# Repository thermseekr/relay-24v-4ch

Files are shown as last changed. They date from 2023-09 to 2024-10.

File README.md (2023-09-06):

# RELAY-24V-4CH

Relay board with 4x 24 VDC relays. This board is designed to be used togheter with [ESP-24V-16CH](https://github.com/thermseekr/esp-24v-16ch) and [ESP-24V-32CH](https://github.com/thermseekr/esp-24v-32ch), but can be driven by any 24V control circuit compatible with NPN inputs.

The dimensions are such that the boards can be mounted on a PCB DIN rail holder from the Brazilian manufacturer Metaltex, check [here](https://www.metaltex.com.br/produtos/componentes/suportes/sp7-suporte-para-montagem-de-placa-de-circuito-impresso-em-trilho-din) for details.

Board V1 uses Omron 16A relays and is limited to 12A/channel, board V2 uses Omron 10A relays and is limited to 8A/channel. The current limits are imposed per copper trace capacity.

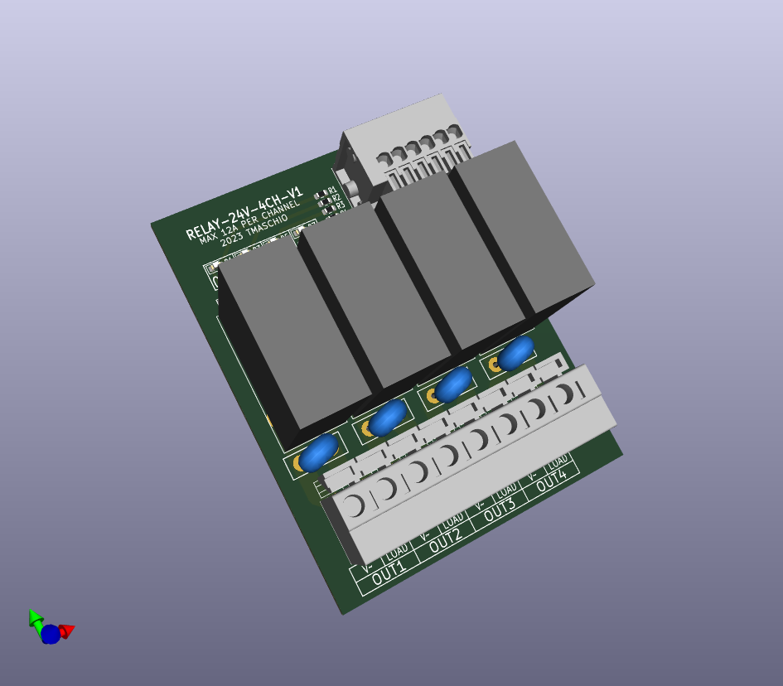
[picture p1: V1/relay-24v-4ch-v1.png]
RELAY-24V-4CH V1


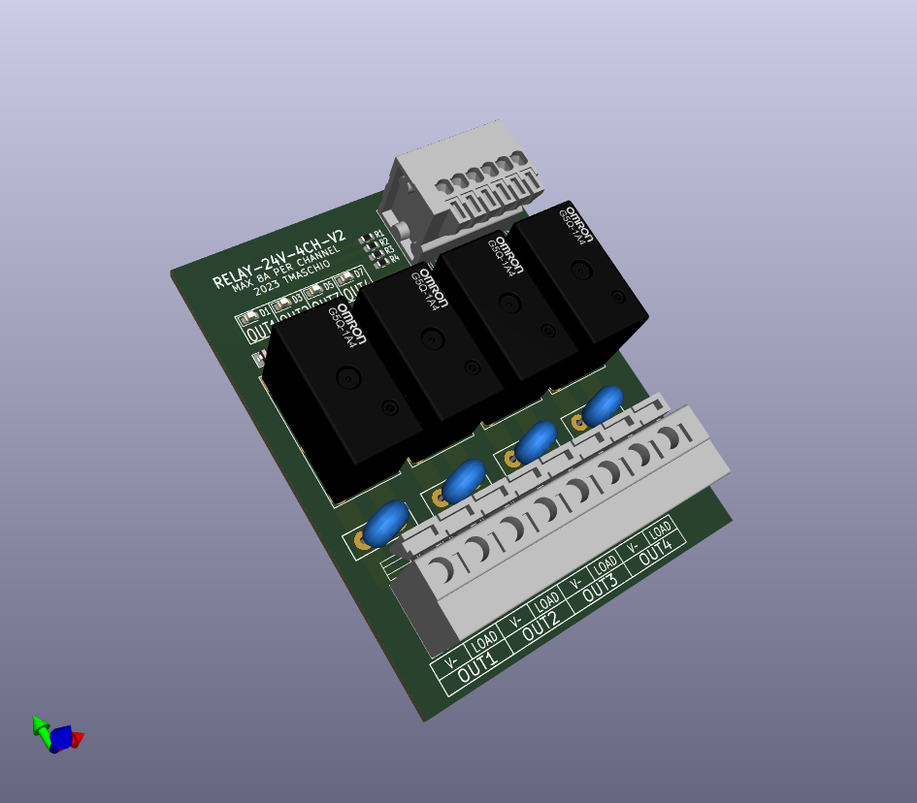
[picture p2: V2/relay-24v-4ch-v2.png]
RELAY-24V-4CH V2


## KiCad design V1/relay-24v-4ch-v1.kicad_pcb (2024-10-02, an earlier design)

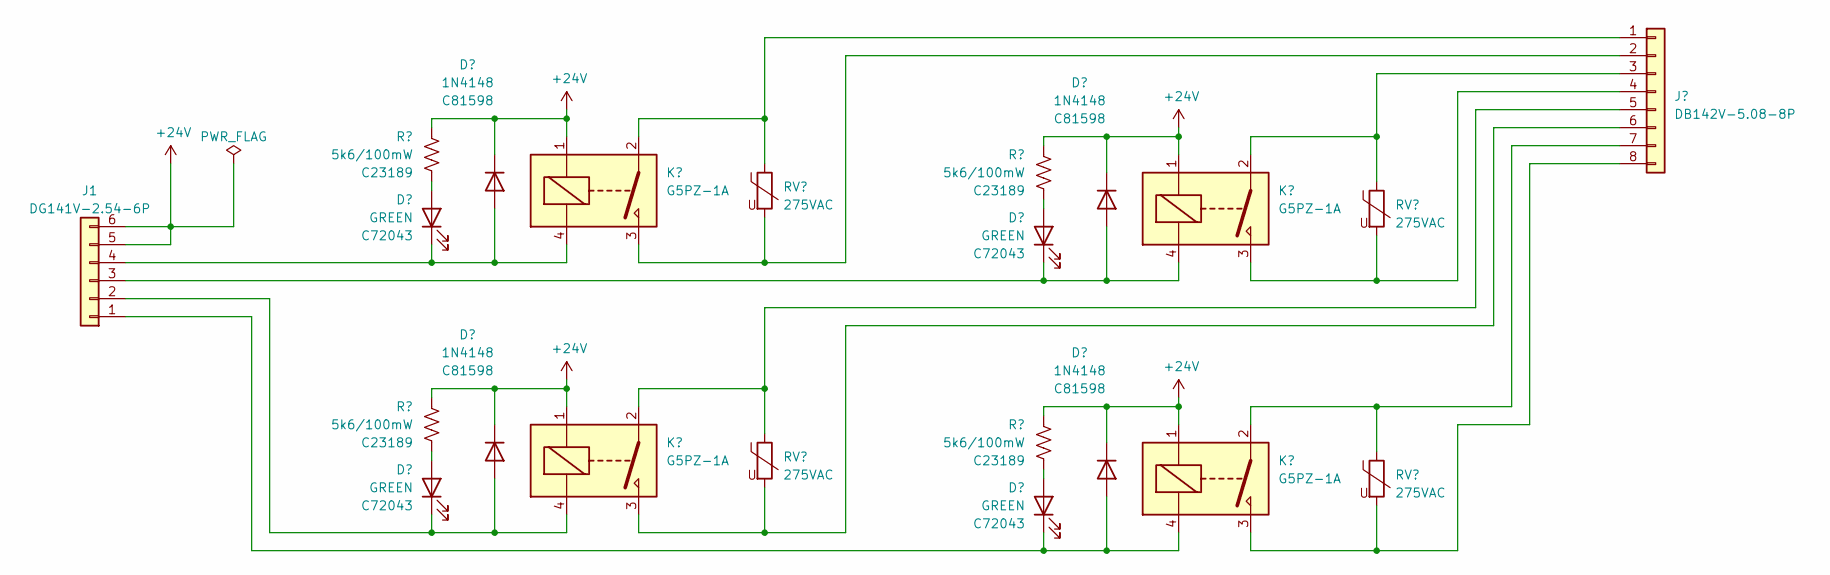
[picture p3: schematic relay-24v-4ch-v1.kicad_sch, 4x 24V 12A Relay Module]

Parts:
D1, D3, D5, D7: GREEN; LED_0603_1608Metric; Mfr PN 19-217/GHC-YR1S2/3T; LCSC Part # C72043
D2, D4, D6, D8: 1N4148; D_SOD-123; Mfr PN 1N4148W; LCSC Part # C81598
J1: DG141V-2.54-6P; TerminalBlock_Dibo_DB141V-2.54-6P_1x06_P2.54mm_Vertical; Mfr PN DB141V-2.54-5P; JLCPCB BOM 1
J2: DB142V-5.08-8P; TerminalBlock_Dibo_DB142V-5.08-8P_1x08_P5.08mm_Vertical; Mfr PN DB142V-5.08-8P; JLCPCB BOM 1
K1, K2, K3, K4: G5PZ-1A; Relay_SPST_Omron_G5PZ-1A; Mfr PN G5PZ-1A; JLCPCB BOM 0
R1, R2, R3, R4: 5k6/100mW; R_0603_1608Metric; Mfr PN 0805W8F4701T5E; LCSC Part # C23189
RV1, RV2, RV3, RV4: 275VAC; RV_Disc_D9.50mm_W3.6mm_P5.08mm; Mfr PN RM07D431KC1IE100; JLCPCB BOM 1

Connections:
+24V: D2.1 (K), D4.1 (K), D6.1 (K), D8.1 (K), J1.5, J1.6, K1.1, K2.1, K3.1, K4.1, R1.1, R2.1, R3.1, R4.1
unnamed: D1.2 (A), R1.2
unnamed: D1.1 (K), D2.2 (A), J1.4, K1.4
unnamed: D3.2 (A), R2.2
unnamed: D3.1 (K), D4.2 (A), J1.3, K2.4
unnamed: D5.2 (A), R3.2
unnamed: D5.1 (K), D6.2 (A), J1.2, K3.4
unnamed: D7.2 (A), R4.2
unnamed: D7.1 (K), D8.2 (A), J1.1, K4.4
unnamed: J2.1, K1.2, RV1.1
unnamed: J2.2, K1.3, RV1.2
unnamed: J2.3, K2.2, RV2.1
unnamed: J2.4, K2.3, RV2.2
unnamed: J2.5, K3.2, RV3.1
unnamed: J2.6, K3.3, RV3.2
unnamed: J2.7, K4.2, RV4.1
unnamed: J2.8, K4.3, RV4.2

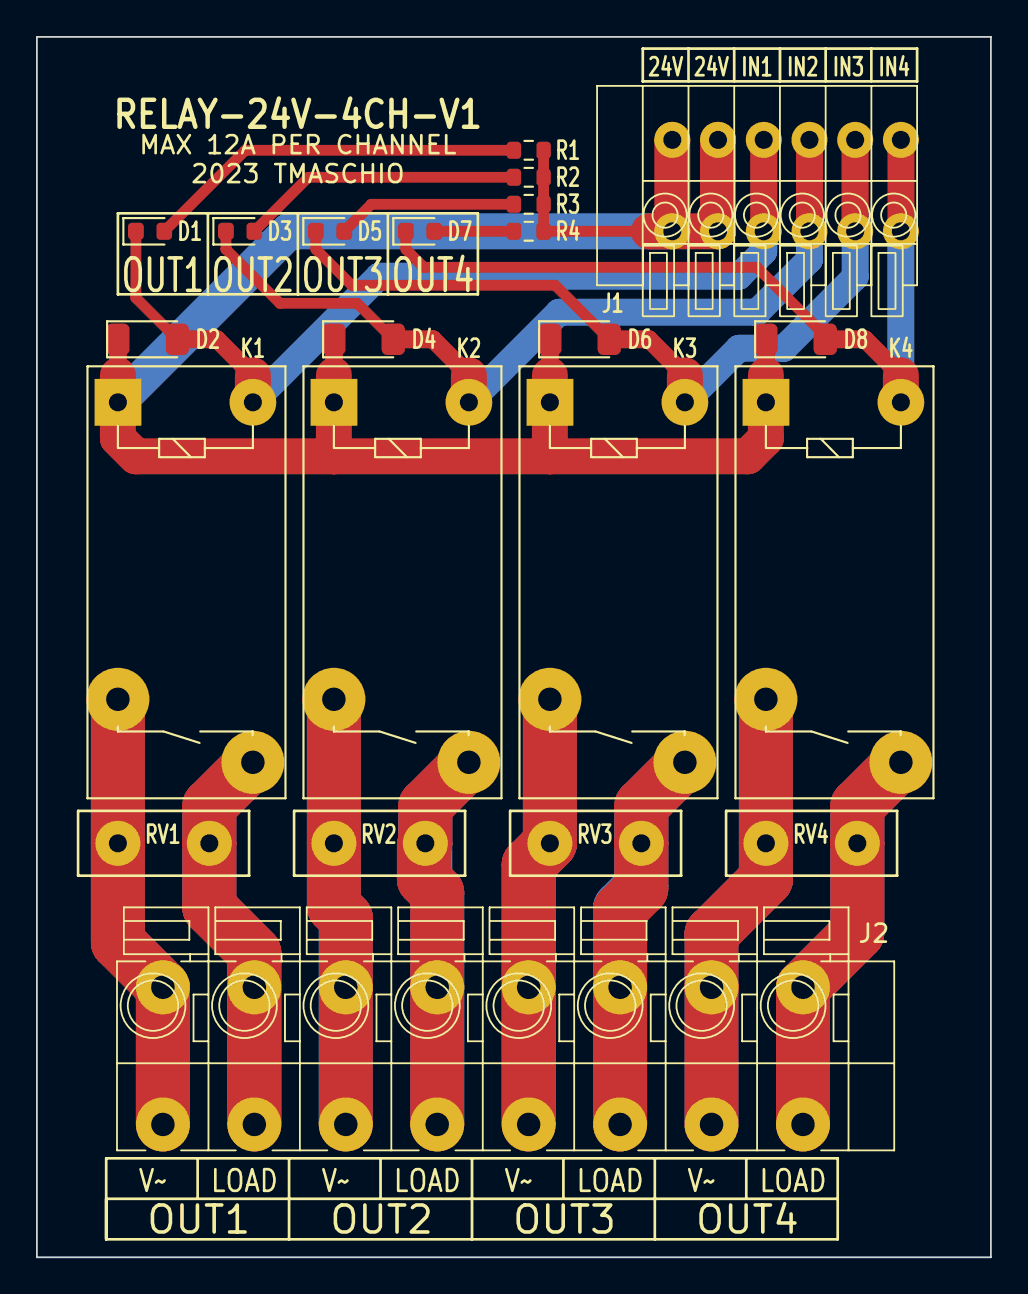
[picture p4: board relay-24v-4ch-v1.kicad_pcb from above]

Board: 2 copper layers, 53.0 x 67.8 mm, 22 parts (0 on the bottom side), 17 nets.

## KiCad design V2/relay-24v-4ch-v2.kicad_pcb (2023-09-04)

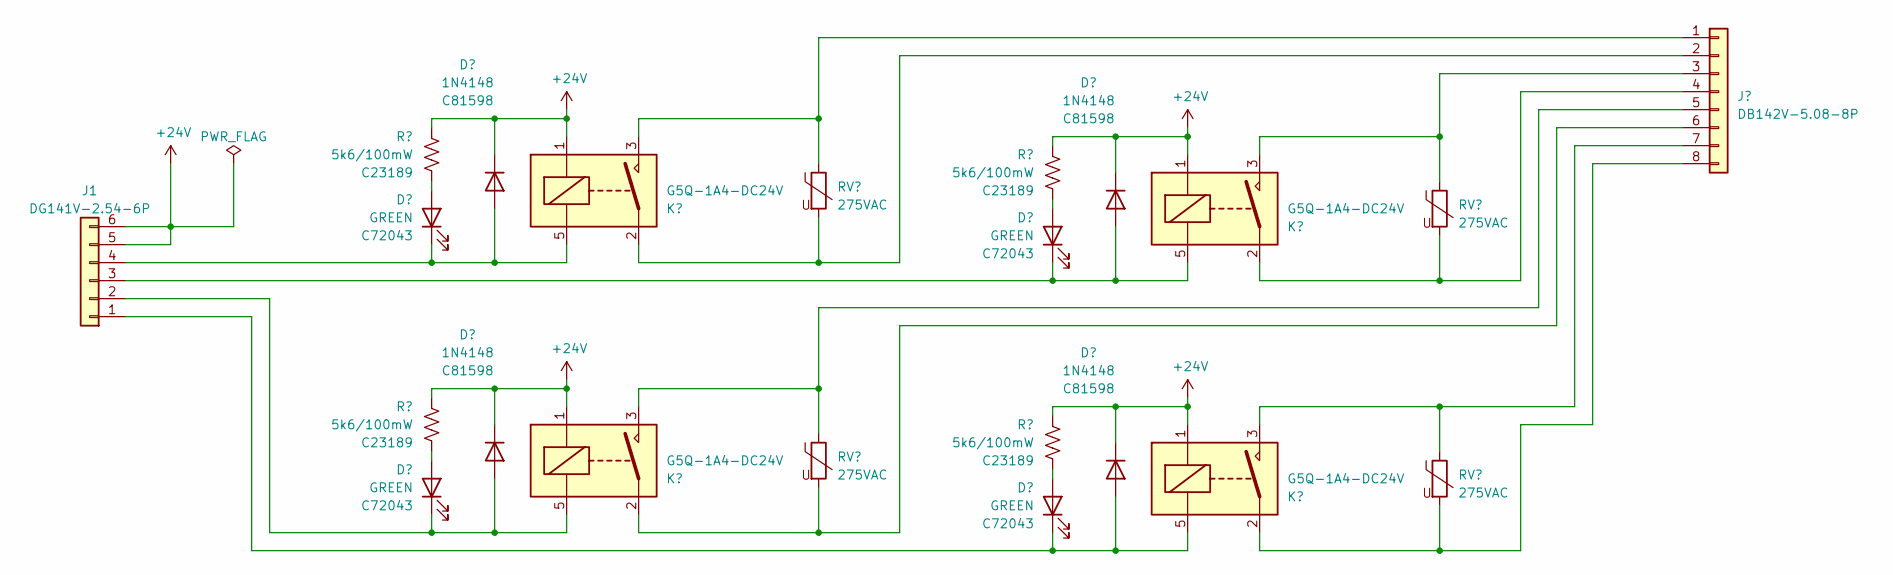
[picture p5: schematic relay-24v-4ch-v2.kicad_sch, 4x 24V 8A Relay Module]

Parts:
D1, D3, D5, D7: GREEN; LED_0603_1608Metric; Mfr PN 19-217/GHC-YR1S2/3T; LCSC Part # C72043
D2, D4, D6, D8: 1N4148; D_SOD-123; Mfr PN 1N4148W; LCSC Part # C81598
J1: DG141V-2.54-6P; TerminalBlock_Dibo_DB141V-2.54-6P_1x06_P2.54mm_Vertical; Mfr PN DB141V-2.54-5P; JLCPCB BOM 1
J2: DB142V-5.08-8P; TerminalBlock_Dibo_DB142V-5.08-8P_1x08_P5.08mm_Vertical; Mfr PN DB142V-5.08-8P; JLCPCB BOM 1
K1, K2, K3, K4: G5Q-1A4-DC24V; Relay_SPST_Omron-G5Q-1A; Mfr PN G5Q-1A4-DC24V; JLCPCB BOM 1
R1, R2, R3, R4: 5k6/100mW; R_0603_1608Metric; Mfr PN 0805W8F4701T5E; LCSC Part # C23189
RV1, RV2, RV3, RV4: 275VAC; RV_Disc_D9.50mm_W3.6mm_P5.08mm; Mfr PN RM07D431KC1IE100; JLCPCB BOM 1

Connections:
+24V: D2.1 (K), D4.1 (K), D6.1 (K), D8.1 (K), J1.5, J1.6, K1.1, K2.1, K3.1, K4.1, R1.1, R2.1, R3.1, R4.1
unnamed: D1.2 (A), R1.2
unnamed: D1.1 (K), D2.2 (A), J1.4, K1.5
unnamed: D3.2 (A), R2.2
unnamed: D3.1 (K), D4.2 (A), J1.3, K2.5
unnamed: D5.2 (A), R3.2
unnamed: D5.1 (K), D6.2 (A), J1.2, K3.5
unnamed: D7.2 (A), R4.2
unnamed: D7.1 (K), D8.2 (A), J1.1, K4.5
unnamed: J2.1, K1.3, RV1.1
unnamed: J2.2, K1.2, RV1.2
unnamed: J2.3, K2.3, RV2.1
unnamed: J2.4, K2.2, RV2.2
unnamed: J2.5, K3.3, RV3.1
unnamed: J2.6, K3.2, RV3.2
unnamed: J2.7, K4.3, RV4.1
unnamed: J2.8, K4.2, RV4.2

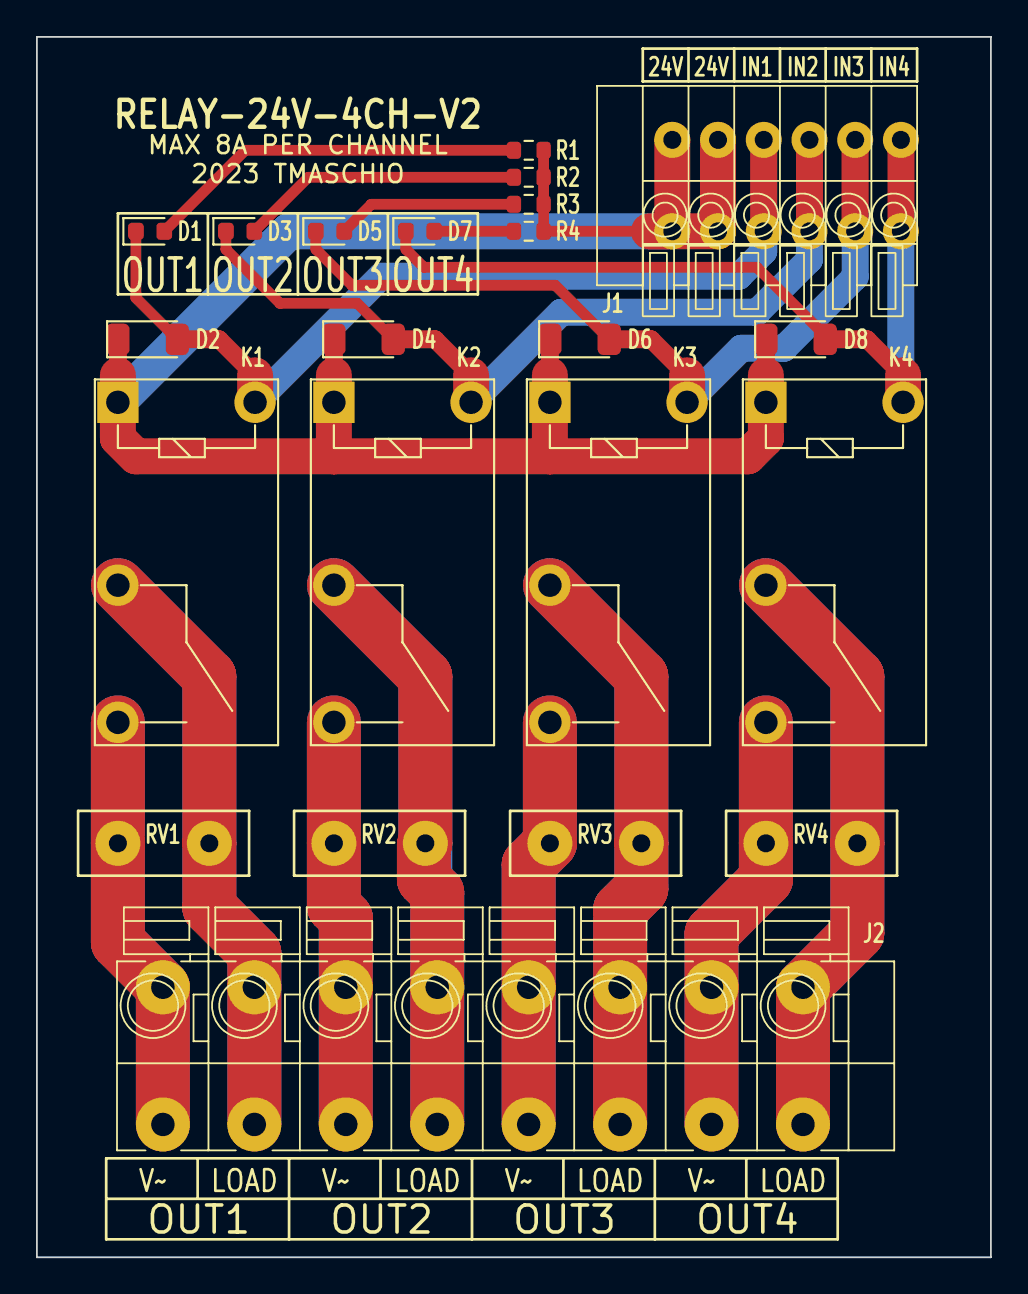
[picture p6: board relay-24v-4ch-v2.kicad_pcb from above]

Board: 2 copper layers, 53.0 x 67.8 mm, 22 parts (0 on the bottom side), 17 nets.

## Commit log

2023-05-22 Update board images
    [Relay-24v-4ch-V1.kicad_pcb, Relay-24v-4ch-V1.kicad_sch]
2023-05-22 Updates for fabrication
    [Relay-24v-4ch-V1.kicad_pcb]
2023-05-23 Adjustments for fabrication
    [Relay-24v-4ch-V1.kicad_pcb, Relay-24v-4ch-V1.kicad_sch]
2023-06-26 Add V2 board with Songle relays.
    [Relay-24v-4ch-V2.kicad_pcb, Relay-24v-4ch-V2.kicad_sch]
2023-08-20 Input connector rotated 180deg
    [Relay-24v-4ch-V2.kicad_pcb, Relay-24v-4ch-V2.kicad_sch]
2023-08-31 Varistor updated
    [Relay-24v-4ch-V2.kicad_sch]
2023-09-02 Design optimization
    [Relay-24v-4ch-V2.kicad_pcb, Relay-24v-4ch-V2.kicad_sch]
2023-09-04 Redone everything
    [Relay-24v-4ch-V1.kicad_pcb, Relay-24v-4ch-V1.kicad_sch, Relay-24v-4ch-V2.kicad_pcb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]
2023-09-04 Minor updates
    [Relay-24v-4ch-V1.kicad_pcb, Relay-24v-4ch-V2.kicad_pcb]
2023-09-04 New board image
2023-09-06 Rename to lowercase
    [small-relay-24v-4ch-v1.kicad_pcb, small-relay-24v-4ch-v1.kicad_sch, small-relay-24v-4ch-v2.kicad_pcb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]
2024-10-02 Update to Kicad 8
    [relay-24v-4ch-v1.kicad_pcb]
